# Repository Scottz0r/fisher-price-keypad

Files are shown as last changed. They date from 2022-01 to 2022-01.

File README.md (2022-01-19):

# Fisher Price Keypad

Turning a Fisher Price Smart Stages keypad into a HID Keyboard.

## Wut?

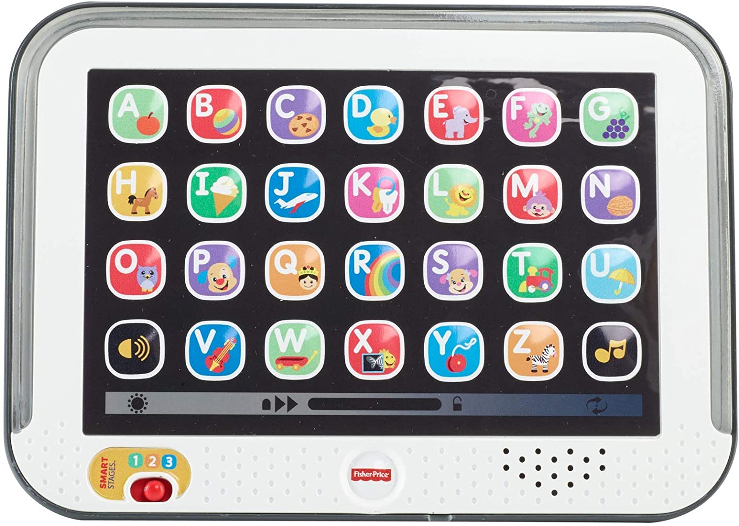
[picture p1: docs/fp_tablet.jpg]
The Keypad


I really wanted to turn a Fisher Price tablet into a keyboard that works over USB for the kicks and giggles.

This turned into a multi-part project where I learned PCB design (with KiCad) as a drop-in replacement to the factory board in the tablet.

The software is made with the Arduino framework to make things easy. The `Keyboard.h` header makes it simple to turn a microcontroller into a HID Keyboard.

## Hardware

* Fisher Price "Smart Stages" Tablet
* Custom PCBs (to replace tablet's PCB)
* Adafruit ItsyBitsy (or any Arduino that can use `Keyboard.h`)

## Custom PCB

I created a custom PCB to replace the board that comes with the tablet. This custom board allows pins or connectors to be soldered so the keypad can be used with an Arduino.

The PCB can be printed with the gerbers in [the gerber zip](fp_tablet_keypad_v1_gerbers.zip). I printed my boards through [OSHPark](https://oshpark.com/). It cost about $9.00 (USD) to print 3 boards.

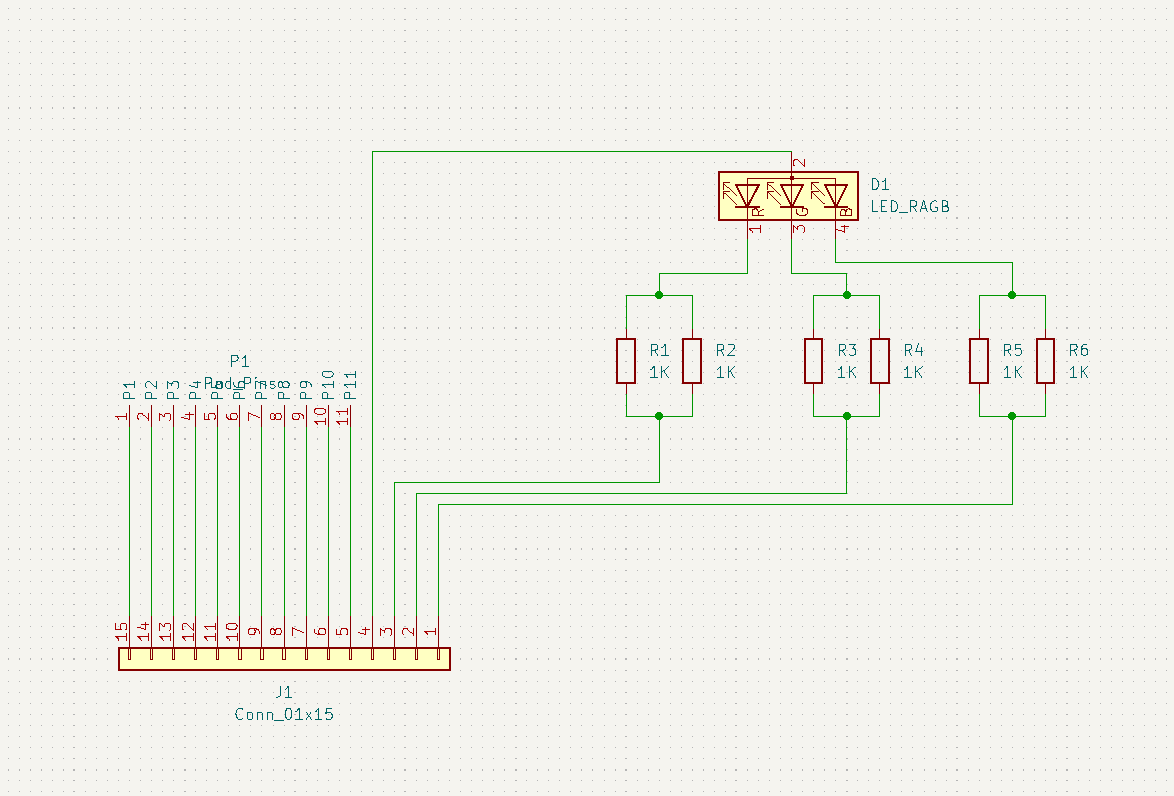
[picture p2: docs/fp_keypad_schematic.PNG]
PCB Schematic


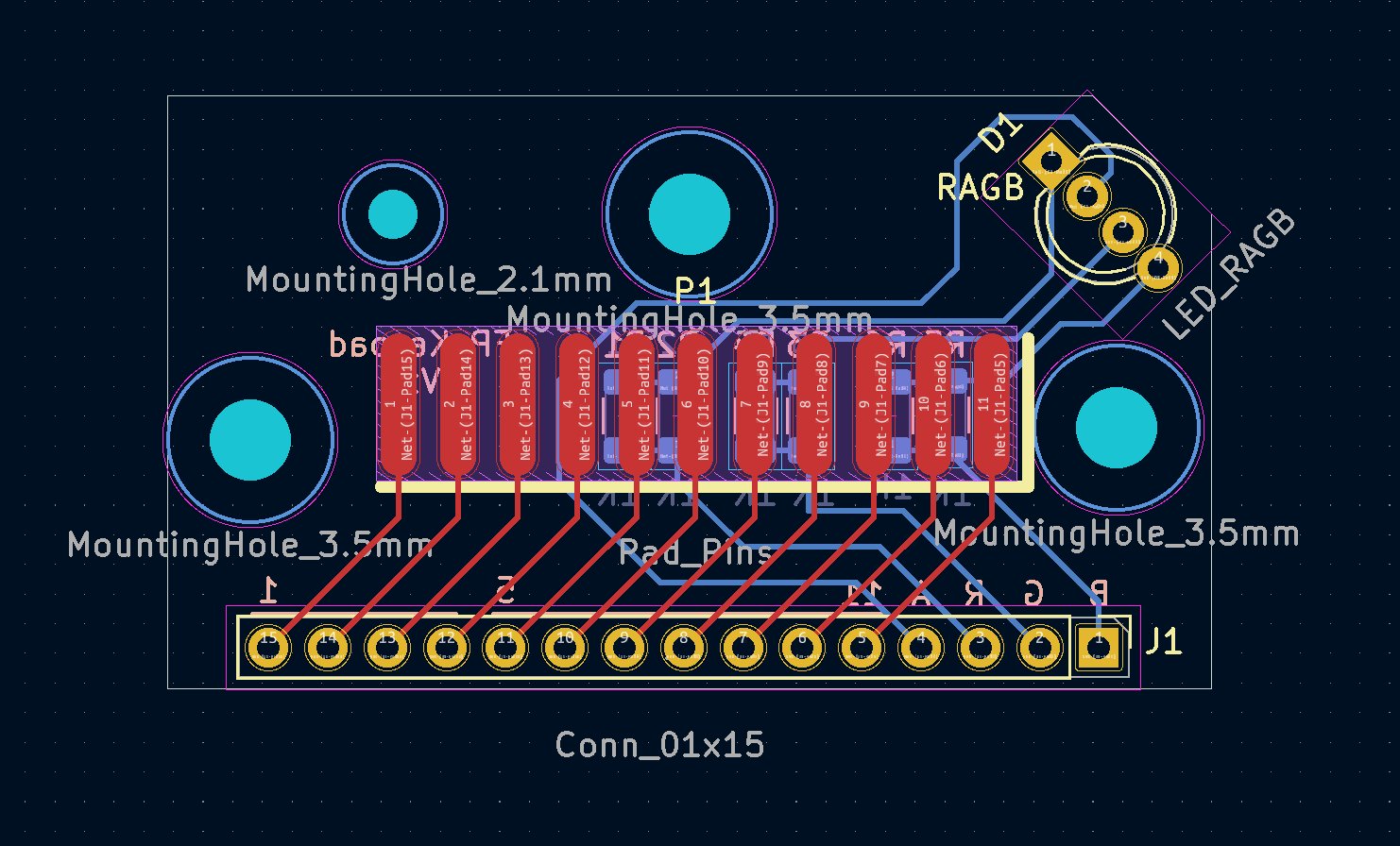
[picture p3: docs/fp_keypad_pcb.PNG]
PCB Layout


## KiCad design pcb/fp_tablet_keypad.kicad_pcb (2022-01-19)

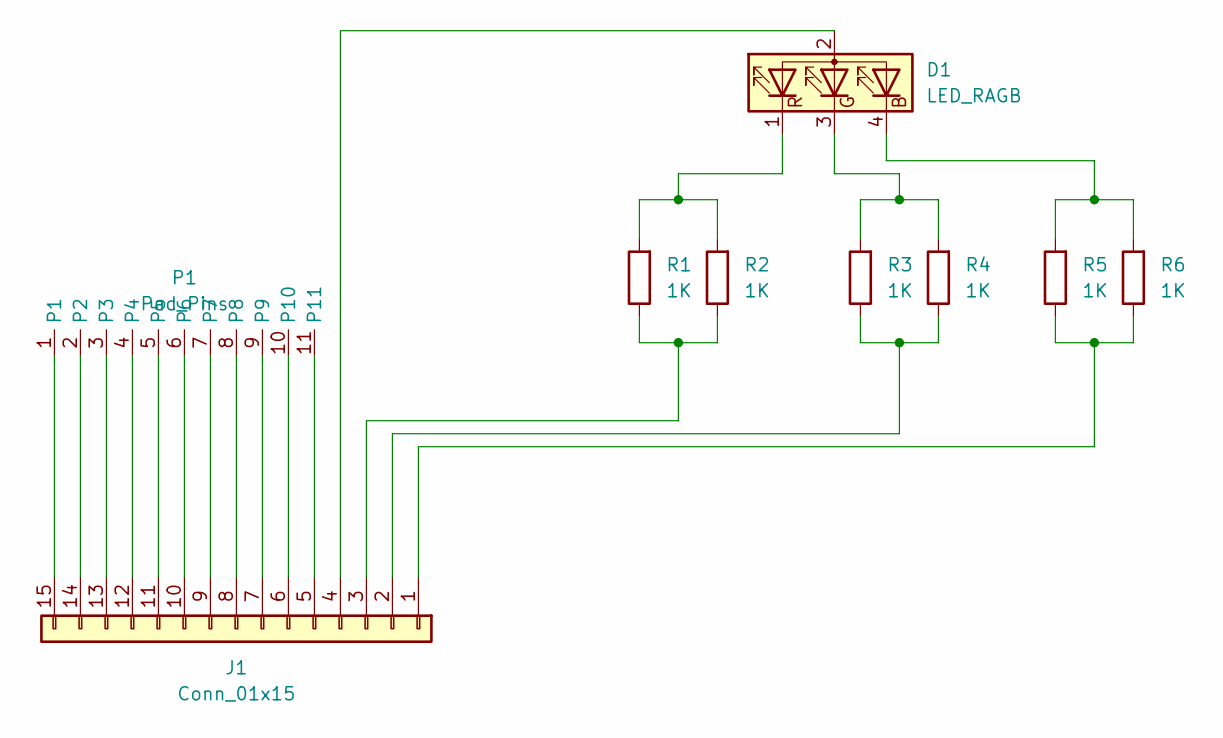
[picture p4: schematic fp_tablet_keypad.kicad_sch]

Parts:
D1: LED_RAGB; LED_D5.0mm-4_RGB_Wide_Pins
J1: Conn_01x15; PinHeader_1x15_P2.54mm_Vertical
P1: Pad_Pins; Keypad Pads
R1, R2, R3, R4, R5, R6: 1K; R_1206_3216Metric

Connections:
unnamed: D1.1 (RK), R1.2, R2.2
unnamed: D1.2 (A), J1.4
unnamed: D1.3 (GK), R3.2, R4.2
unnamed: D1.4 (BK), R5.2, R6.2
unnamed: J1.1, R5.1, R6.1
unnamed: J1.2, R3.1, R4.1
unnamed: J1.3, R1.1, R2.1
unnamed: J1.5, P1.11
unnamed: J1.6, P1.10
unnamed: J1.7, P1.9
unnamed: J1.8, P1.8
unnamed: J1.9, P1.7
unnamed: J1.10, P1.6
unnamed: J1.11, P1.5
unnamed: J1.12, P1.4
unnamed: J1.13, P1.3
unnamed: J1.14, P1.2
unnamed: J1.15, P1.1

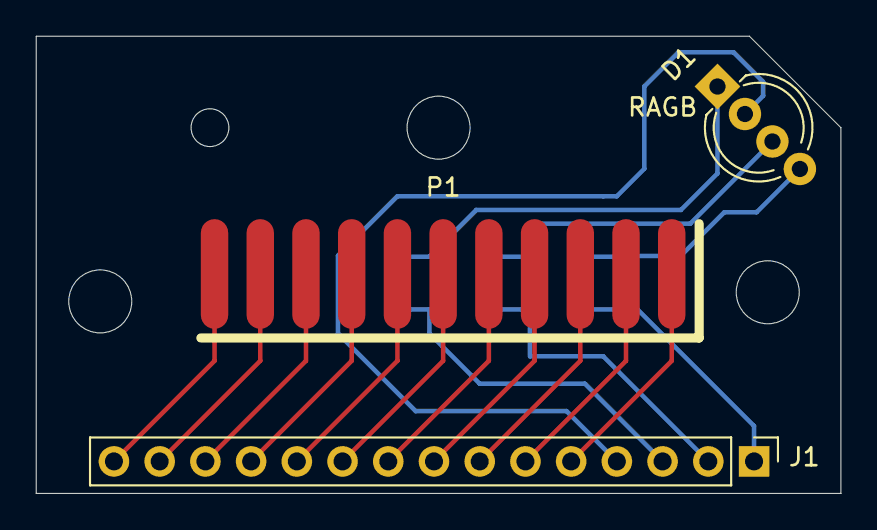
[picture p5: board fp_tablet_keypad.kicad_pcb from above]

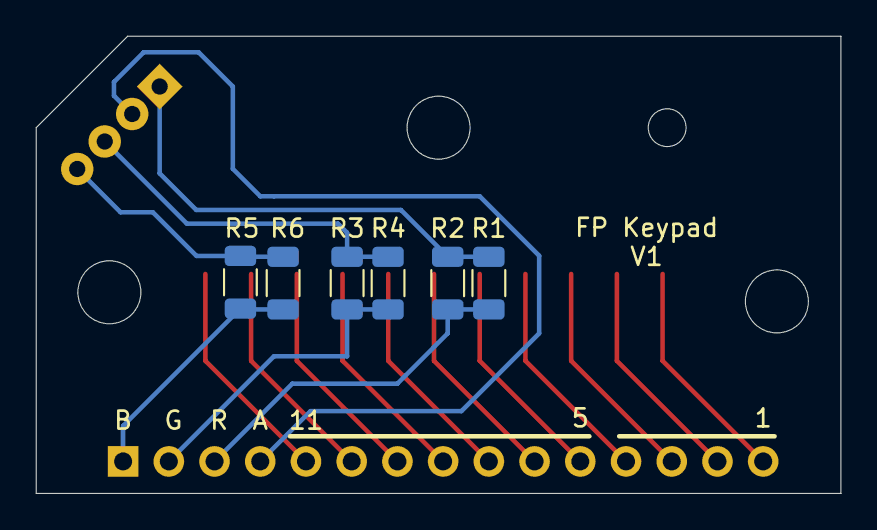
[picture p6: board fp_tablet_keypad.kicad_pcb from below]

Board: 2 copper layers, 44.7 x 25.4 mm, 9 parts (6 on the bottom side), 18 nets.

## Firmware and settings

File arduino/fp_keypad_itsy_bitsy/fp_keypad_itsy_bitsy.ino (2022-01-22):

// Author: Scott Clewell
// January 2022
// Program to turn a Fisher Price "Smart Stages" tablet into a HID Keyboard device.
// Requires a custom PBC (which I have conveniently designed) to replace the PCB that comes with the Keypad.
#include <Arduino.h>
#include <Keyboard.h>

#include "prj_generic_types.h"
#include "color_mapper.h"
#include "globals.h"

using namespace scottz0r;

static constexpr time_type animation_time_ms = 1000;

void setup()
{
    init_led();
    keypad.begin();
    Keyboard.begin();
}

// Main program loop.
void loop()
{
    // Keypad interaction
    char key_result = keypad.process();
    handle_keypress(key_result);

    // Process led. Do after keypress to immediately process color changes.
    led_manager.process();
}

void handle_keypress(char key_result)
{
    if (key_result == Keypad::key_release)
    {
        Keyboard.releaseAll();
    }
    else if(key_result != Keypad::no_key)
    {
        Keyboard.press(key_result);

        const LookUpTable* lut = map_key_to_color(key_result);
        if (lut)
        {
            led_manager.set(*lut, animation_time_ms);
        }
    }
}

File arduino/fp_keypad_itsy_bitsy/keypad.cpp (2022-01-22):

#include "keypad.h"

#include <avr/pgmspace.h>
#include <Arduino.h>
#include "hw_cfg.h"

namespace scottz0r {
    
    static constexpr int row_pins_count = scottz0r_array_size(keypad_row_pins);
    static constexpr int col_pins_count = scottz0r_array_size(keypad_col_pins);

    // Maps key number to ASCII character. The index must match the key index on the keypad,
    // which is found by (r * col_pins_count) + c
    static const char keymap[] PROGMEM = 
    {
        'A',
        'B',
        'C',
        'D',
        'E',
        'F',
        'G',
        'H',
        'I',
        'J',
        'K',
        'L',
        'M',
        'N',
        'O',
        'P',
        'Q',
        'R',
        'S',
        'T',
        'U',
        ' ',
        'V',
        'W',
        'X',
        'Y',
        'Z',
        '\n'
    };
    static constexpr int keymap_size = scottz0r_array_size(keymap);

    Keypad::Keypad()
    {

    }

    void Keypad::begin()
    {
        // Rows set as output, set high.
        for (int i = 0; i < row_pins_count; ++i)
        {
            pinMode(keypad_row_pins[i], OUTPUT);
            digitalWrite(keypad_row_pins[i], HIGH);  
        }

        // Columns input with pullup (Low = on)
        for (int i = 0; i < col_pins_count; ++i)
        {
            pinMode(keypad_col_pins[i], INPUT_PULLUP);
        }

        // Set killswitch as input pulled up. If connected to ground, it will disable the keyboard.
        pinMode(killswitch_pin, INPUT_PULLUP);
    }

    char Keypad::process()
    {
        time_type now = millis();
        time_type elapsed = now - m_last_scan;

        if (elapsed < POLL_RATE)
        {
            return no_key;
        }

        char result = no_key;
        int key = scan_pad();

        if (key >= 0 && key < keymap_size)
        {
            result = handle_keydown(key);
        }
        else
        {
            if (m_prev_key_code != NO_BUTTON)
            {
                result = key_release;
            }

            // No key pressed. Clear last key.
            m_prev_key_code = NO_BUTTON;            
        }

        m_last_scan = now;

        return result;
    }

    // Scan the keypad for a pressed button. This will return after finding the first button pressed.
    // This assumes the columns are inputs with pullups and the rows are outputs.
    int Keypad::scan_pad()
    {
        int result = NO_BUTTON;

        for (int r = 0; r < row_pins_count; ++r)
        {
            // Write row low.
            int row_pin = keypad_row_pins[r];
            digitalWrite(row_pin, LOW);

            // Read columns to see if any are pulled low.
            for (int c = 0; c < col_pins_count; ++c)
            {
                int col_pin = keypad_col_pins[c];
                int pin_value = digitalRead(col_pin);

                // These pins are pulled up, so low means they are connected to ground via the row pin.
                if (!pin_value)
                {
                    // Set the button number, counting by rows then columns. Stop the column looping. Cannot use a
                    // return here because the pin still needs to be reset to the default state of HIGH.
                    result = (r * col_pins_count) + c;
                    break;
                }
            }

            // Write row back high after polling columns.
            digitalWrite(row_pin, HIGH);

            // Stop row loops if a button found.
            if (result != NO_BUTTON)
            {
                break;
            }
        }

        return result;
    }

    // Handle a key being pressed, sending the keystroke to the deviced plugged in via USB.
    char Keypad::handle_keydown(int key_code)
    {
        // Killswitch low = keyboard disabled.
        int is_killed = digitalRead(killswitch_pin);
        if (!is_killed)
        {
            return no_key;
        }

        // Do nothing if the same key is pressed.
        if (m_prev_key_code == key_code)
        {
            return no_key;
        }

        // Get ASCII character representation.
        char c = (char)pgm_read_byte_near(keymap + key_code);

        // Save last key press to avoid double pressing. This also helps with debounce, too.
        m_prev_key_code = key_code;

        return c;
    }
}

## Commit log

2022-01-19 Added initial files
    Adding files to project. This is a simple "v1" that works as a keypad, but without a LED.
    [fp_tablet_keypad.kicad_pcb, fp_tablet_keypad.kicad_sch]
2022-01-22 Added initial files for lighting RGB LED with keypress.
2022-01-22 Fixes and support for all LED colors
    [fp_keypad_itsy_bitsy.ino]
